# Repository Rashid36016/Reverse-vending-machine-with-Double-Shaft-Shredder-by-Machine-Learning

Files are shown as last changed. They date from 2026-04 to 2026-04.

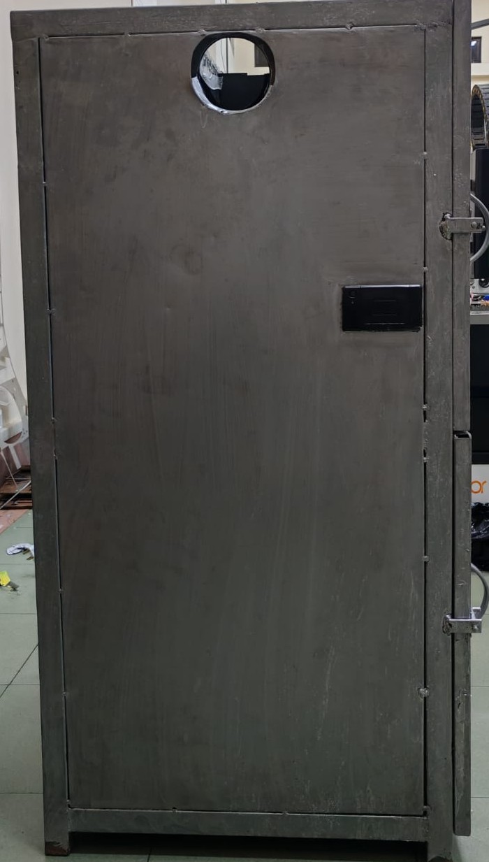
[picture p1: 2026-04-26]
Photos/Front view.jpeg

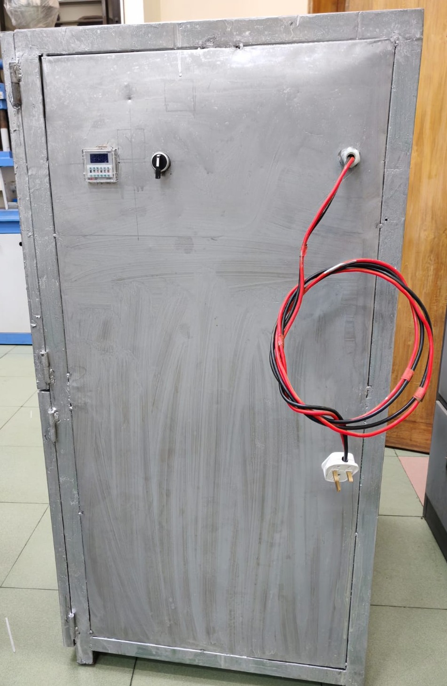
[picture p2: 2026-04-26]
Photos/Back view.jpeg

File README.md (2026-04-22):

# Reverse-vending-machine-with-Double-Shaft-Shredder-by-Machine-Learning

## Project Overview

This project presents a smart Reverse Vending Machine (RVM) designed to accept recyclable plastic bottles, verify them using artificial intelligence and sensor-based validation, and process them using a double shaft shredding mechanism.

The system integrates AI, embedded systems, and mechanical design to create an efficient and automated recycling solution.

---

## Objectives

* To automate plastic bottle collection and validation
* To reduce waste volume through shredding
* To prevent invalid inputs using AI and sensors
* To develop an integrated mechatronic recycling system

---

## Key Features

* AI-based object detection using YOLO
* Real-time image capture using ESP32-S3 CAM
* Sensor-based validation (IR / proximity)
* Double shaft shredding system
* Automatic and timed motor control
* Feedback system (LED / thermal printer)

---

## System Architecture

### 1. Detection Layer (Artificial Intelligence)

The system captures images using the ESP32-S3 CAM and processes them through a YOLO-based object detection model to identify whether the inserted object is a valid plastic bottle.

### 2. Validation Layer (Sensors)

Sensors are used to confirm the presence and correctness of the object, reducing false positives and ensuring reliability.

### 3. Processing Layer (Mechanical System)

A double shaft shredder is used to crush the bottle. This reduces volume and prepares the material for recycling.

---

## Working Principle

1. The user inserts a plastic bottle
2. The camera captures an image
3. The YOLO model performs object detection
4. Sensors validate the input
5. If the object is valid:

   * The shredder motor is activated
6. The bottle is shredded
7. The system provides output feedback

---

## Shredder Mechanism

The system utilizes a double shaft shredding mechanism:

* Two shafts rotate in opposite directions
* Blades mounted on the shafts grip and cut the material
* This configuration improves efficiency and reduces the risk of jamming

---

## Control System

### Automatic Mode

The shredder is activated automatically upon successful detection and validation.

### Timed Mode

The motor operates for a predefined duration to prevent overload and ensure safe operation.

---

## Hardware Components

* ESP32
* ESP32-S3 CAM
* Motor driver
* DC motors
* IR / proximity sensors
* Thermal printer
* Power supply (SMPS)

---

## Software Components

* Arduino IDE (ESP32 programming)
* Python (YOLO model implementation)
* Embedded C/C++

---

## Applications

* Smart recycling systems
* Educational institutions
* Commercial areas (shopping malls)
* Smart city infrastructure

---

## Advantages

* Encourages recycling behavior
* Reduces waste volume
* Minimizes human intervention
* Integrates AI with mechanical processing

---

## Future Work

* Integration of a reward-based system
* Mobile application support
* Cloud-based monitoring
* Improved detection accuracy

---

## Author

Rashid
Industrial and Production Engineering Student

---

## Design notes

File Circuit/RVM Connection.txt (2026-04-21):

RVM System Connection:

Servo-1: Signal -> GPIO 4 , VCC -> Buck 5V , GND -> Buck GND
Servo-2: Signal -> GPIO 5 , VCC -> Buck 5V , GND -> Buck GND

Green LED   VCC -> GPIO 12 , GND -> SMPS GND
Red LED     VCC -> GPIO 13 , GND -> SMPS GND
Red LED     VCC -> GPIO 18 , GND -> SMPS GND
Orange LED  VCC -> GPIO 21 , GND -> SMPS GND
Blue LED    VCC -> GPIO 22 , GND -> SMPS GND
White LED   VCC -> GPIO 23 , GND -> SMPS GND

Thermal Printer: RX -> RX , TX -> TX , VCC -> SMPS 12v , GND -> SMPS GND

ESP32: VCC -> Buck 5V , GND -> Buck GND

ESSP32 S3 CAM: USB Port to LAPTOP

Meaning of LED:-
Ready        -> Green LED
STOP         -> Red LED
PROCESSING   -> Yellow LED
SERVO OPEN   -> Orange LED
SERVO CLOSE  -> Blue LED
PRINT        -> White LED

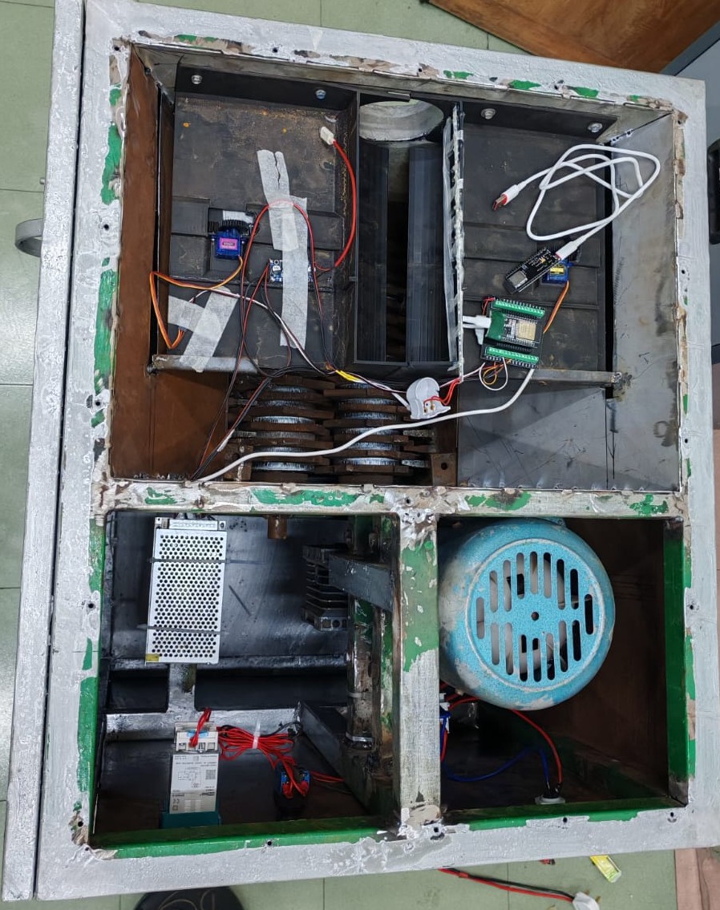
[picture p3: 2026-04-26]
Photos/Top view.jpeg

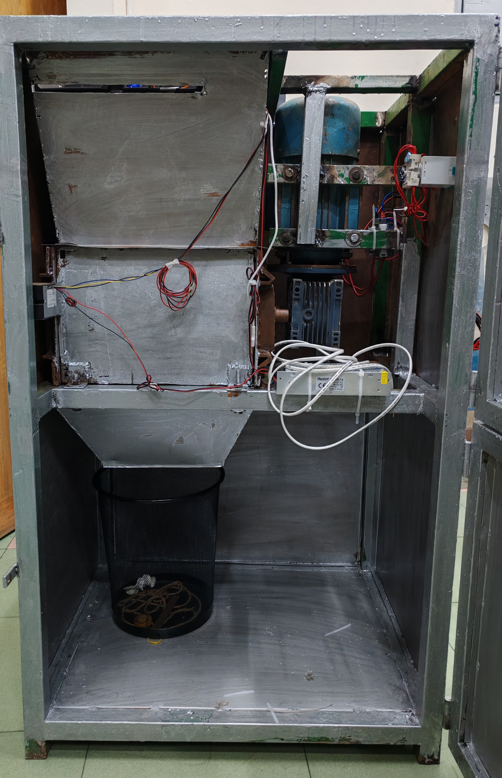
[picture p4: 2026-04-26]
Photos/Side view.jpeg

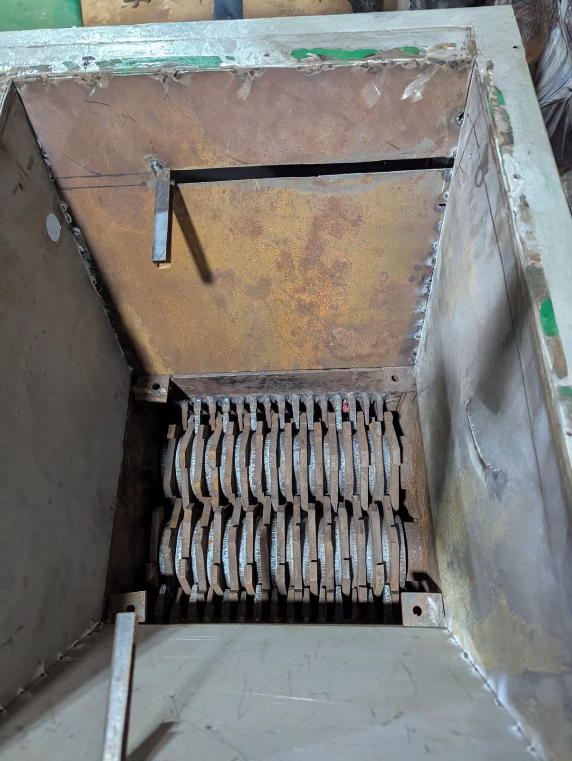
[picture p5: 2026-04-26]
Photos/Top view of the Shredder.jpeg

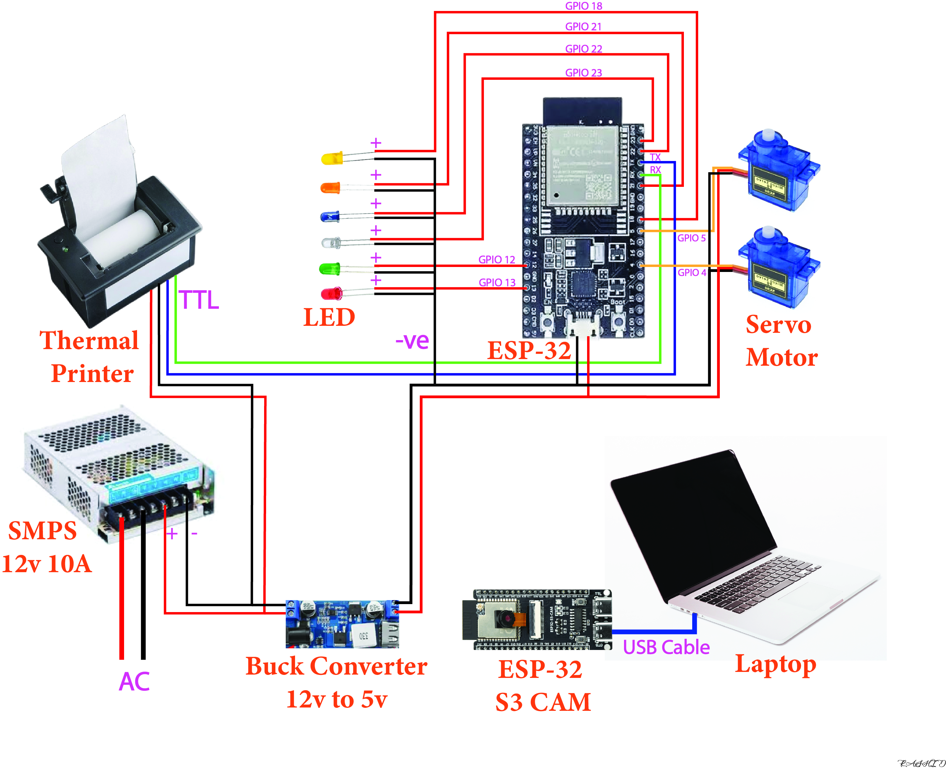
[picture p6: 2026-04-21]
Circuit/Circuite.jpg

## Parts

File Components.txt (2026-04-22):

Components

1. ESP32 Development Board
2. ESP32-S3 Module
3. Servo Motor × 2
4. SMPS Power Supply (12V, 10A)
5. Buck Converter (12V to 5V)
6. Type-C USB Cable
7. Jumper Wires
8. Connecting Wires
9. Thermal Printer
10. LEDs (Red, Blue, Green, White, Yellow, Orange)
11. Laptop / Computer

Tools and Equipment

1. Soldering Iron
2. Soldering Lead
3. Flux (Resin)
4. Double-Sided Tape
5. Glue Gun with Glue Sticks
6. Wire Cutter
7. Anti Cutter
8. Screwdriver 
9. Super Glue
10. 3D Printer

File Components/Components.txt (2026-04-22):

Components

1. ESP32 Development Board
2. ESP32-S3 Module
3. Servo Motor × 2
4. SMPS Power Supply (12V, 10A)
5. Buck Converter (12V to 5V)
6. Type-C USB Cable
7. Jumper Wires
8. Connecting Wires
9. Thermal Printer
10. LEDs (Red, Blue, Green, White, Yellow, Orange)
11. Laptop / Computer
13. Steel Sheet for Frame
14. Shredder Teeth With Shaft (twin shaft)
15. Main Switch
16. Plug × 2
17. AC Motor (2Hp)
18. Gearbox
19. Contantor
20. Overload Relay
21. Time Relay
22. Emergency Stop Button
23. VFD

Tools and Equipment

1. Soldering Iron
2. Soldering Lead
3. Flux (Resin)
4. Double-Sided Tape
5. Glue Gun with Glue Sticks
6. Wire Cutter
7. Anti Cutter
8. Screwdriver 
9. Super Glue
10. 3D Printer

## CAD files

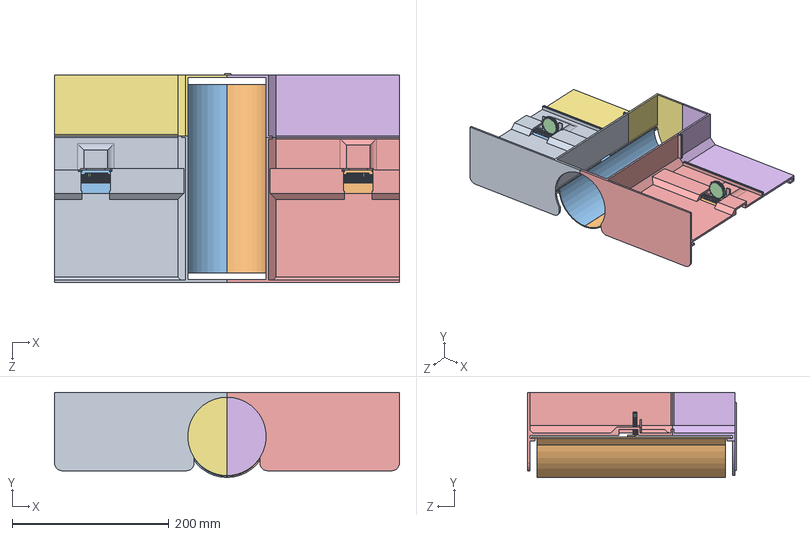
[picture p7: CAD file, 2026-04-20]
3D Parts/3D STLPRT file/Assem1.SLDASM
440.4 x 108.5 x 267.0 mm
Base Left - Back
Base Right - Back
Base Right - Front
Gear x 2
Rack Left
Rack Right
Base Left - Front

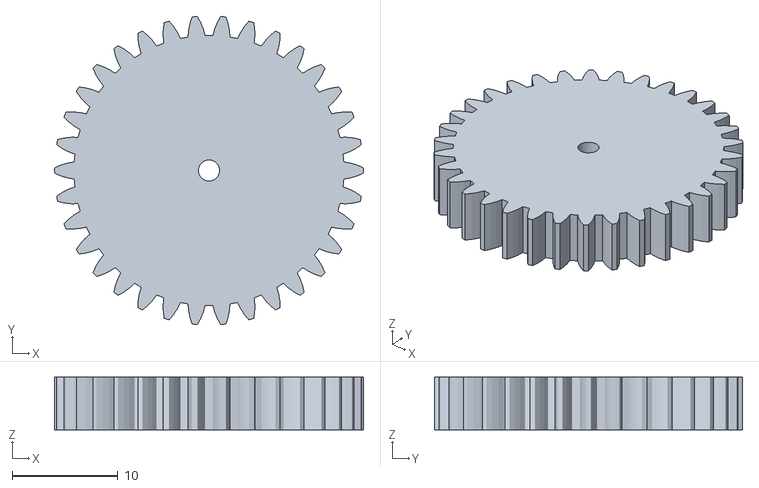
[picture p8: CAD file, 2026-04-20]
3D Parts/3D STL file/Gear.STL
29.2 x 29.1 x 5.00

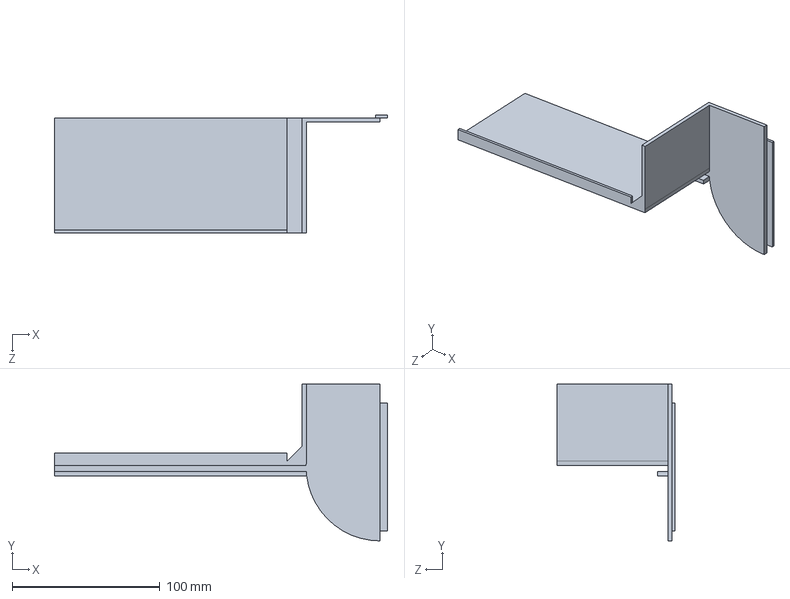
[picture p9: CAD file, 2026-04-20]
3D Parts/3D STLPRT file/Base Left - Back.SLDPRT
225.2 x 106.1 x 80.0 mm

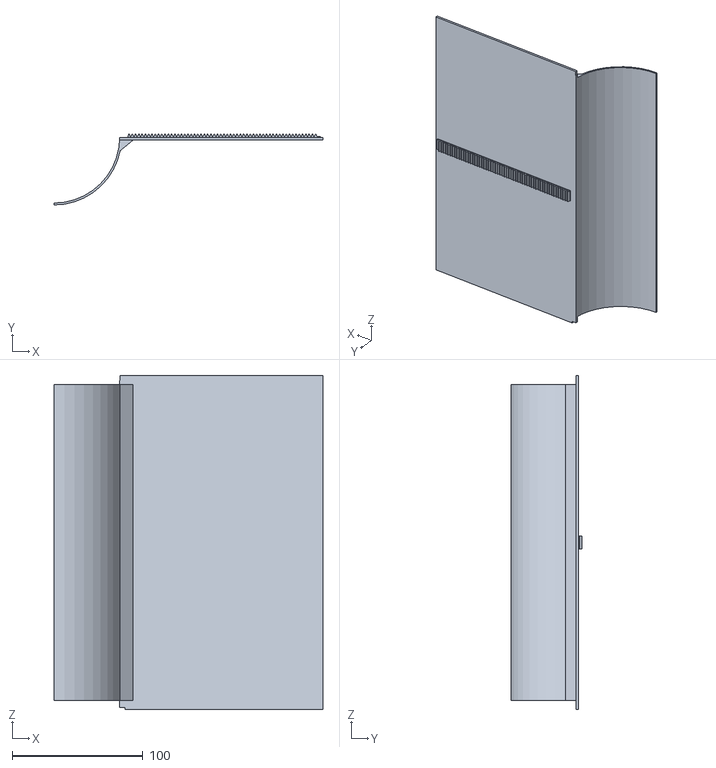
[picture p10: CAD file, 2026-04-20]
3D Parts/3D STL file/Rack Right-2.STL
205.3 x 54.2 x 255.0

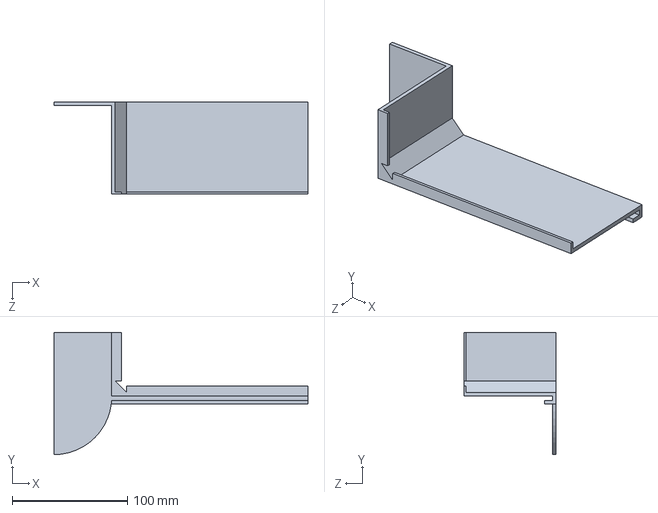
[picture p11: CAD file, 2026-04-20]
3D Parts/3D STLPRT file/Base Right - Back.SLDPRT
220.2 x 106.1 x 80.0 mm

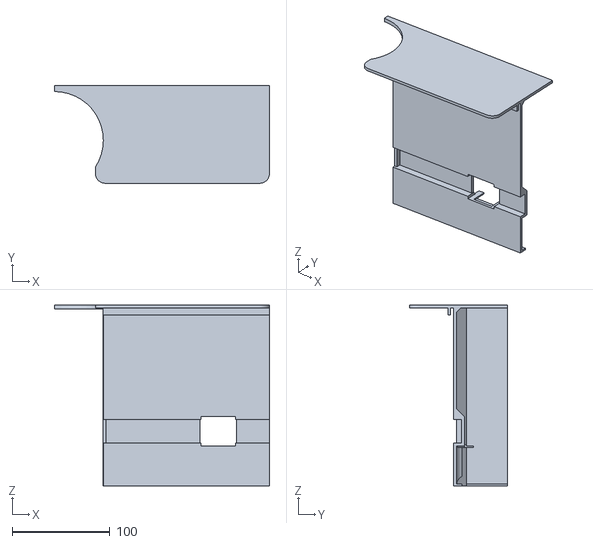
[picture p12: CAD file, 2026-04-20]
3D Parts/3D STL file/Base Right - Front-1.STL
220.2 x 100.0 x 185.0

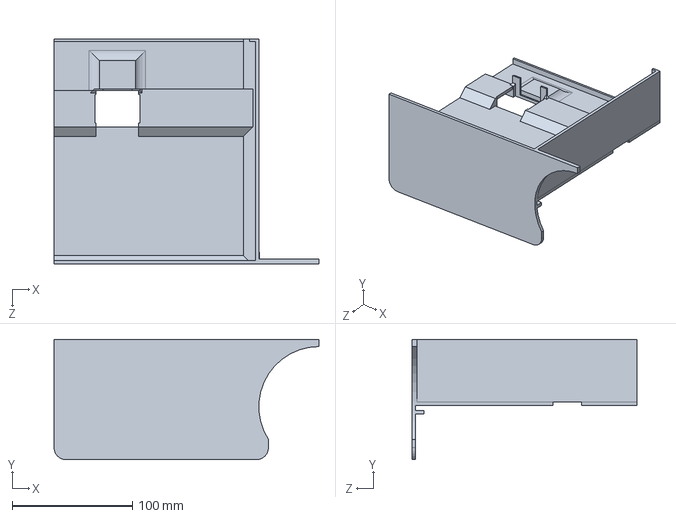
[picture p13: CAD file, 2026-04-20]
3D Parts/3D STLPRT file/Base Left - Front.SLDPRT
220.2 x 100.0 x 187.0 mm

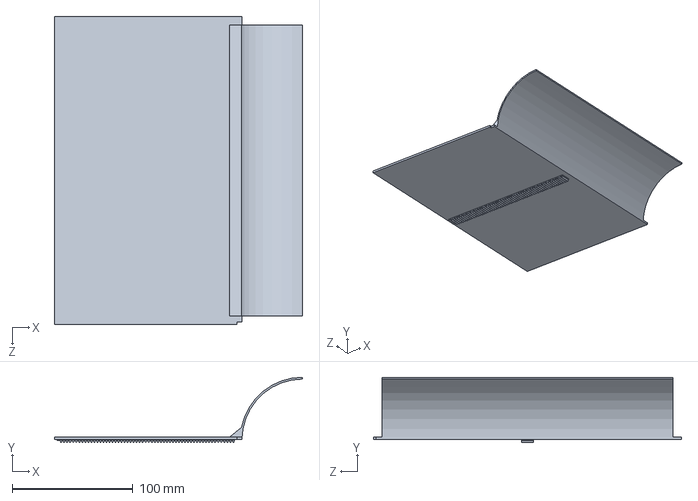
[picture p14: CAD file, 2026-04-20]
3D Parts/3D STLPRT file/Rack Left.SLDPRT
205.3 x 54.2 x 255.0 mm

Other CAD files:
3D Parts/3D STL file/Base Left - Back-1.STL
3D Parts/3D STLPRT file/Base Right - Front.SLDPRT
3D Parts/3D STL file/Base Right - Back-1.STL
3D Parts/3D STL file/Base Left - Front-1.STL
3D Parts/3D STLPRT file/Gear.SLDPRT
3D Parts/3D STL file/Rack Left-2.STL
3D Parts/3D STLPRT file/Rack Right.SLDPRT

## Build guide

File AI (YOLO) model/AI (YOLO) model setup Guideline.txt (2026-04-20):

Windows 11 এ YOLO setup + check 👇

STEP 1: Python install (Windows 11)
Download: 👉 https://www.python.org/downloads/windows/
Install করার সময় IMPORTANT: ✔ “Add Python to PATH” ✔️ (এইটা অবশ্যই tick দাও)

STEP 2: Test Python install
CMD (Command Prompt) খুলে লিখো:
python --version
Output আসবে → দেখতে পাবে Python version

STEP 3: YOLO + Libraries install
CMD এ এইটা paste করো: pip install ultralytics opencv-python requests
Problem হলে fix
❌ pip not recognized
python -m pip install ultralytics 

STEP 4: Test YOLO install
CMD এ লিখো: yolo
Output আসলে → install OK

STEP 4: Simple YOLO test (image)
Open Notepad → Paste 
////
Codes is in next folder Folder Name: YOLO model codes File Name: test
///
ক্লিক Save → Name: test.py → Save as type: All files → Path: C - User - Lenovo - yolo_project

Step 5: Run করো
CMD (Command Prompt) খুলে লিখো:
python test.py
Result window open হবে
Object দেখতে পাবে

STEP 6: Camera test (PC webcam)
Open Notepad → Paste below codes
///
Codes is in next folder Folder Name: YOLO model codes File Name: stream_test
///
ক্লিক Save → Name: stream_test.py → Save as type: All files → Path: C - User - Lenovo - yolo_project

STEP 7: ESP32 Cam stream test
CMD (Command Prompt) খুলে লিখো:
stream_test.py
Result window open হবে
Object detect দেখতে পাবে

STEP 8: Filter Bottle test (PC webcam)
Open Notepad → Paste below codes
///
Codes is in next folder Folder Name: YOLO model codes File Name: filtered_yolo
///
ক্লিক Save → Name: filtered_yolo.py → Save as type: All files → Path: C - User - Lenovo - yolo_project

STEP 9: ESP32 Cam stream test
CMD (Command Prompt) খুলে লিখো:
filtered_yolo.py
Result window open হবে
Only bottle detect করবে।

STEP 10: Main code (It will use from now)
Open Notepad → Paste below codes
///
Codes is in next folder Folder Name: YOLO model codes File Name: main_control
///
ক্লিক Save → Name: main_control.py → Save as type: All files → Path: C - User - Lenovo - yolo_project

STEP 11: ESP32 Activities
Connect ESP32 with PC and connect LEDs with ESP32
CMD (Command Prompt) খুলে লিখো:
main_control.py
Result window open হবে
ESP32 এর activities দেখতে পাবে।

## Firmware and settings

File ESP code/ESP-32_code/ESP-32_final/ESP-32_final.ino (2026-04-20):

#include <ESP32Servo.h>

// =============================
// ===== USER CHANGE ZONE =====
// =============================

#define SERVO1_PIN 4
#define SERVO2_PIN 5

#define READY_LED 12        //Ready for taking bottle
#define STOP_LED 13         //Not ready for taking bottle
#define PROCESSING_LED 18   //Processing 
#define SERVO_OPEN_LED 21   //Get is opening
#define SERVO_CLOSE_LED 22  //Get is closing
#define PRINT_LED 23        //Voucher printing

// Printer UART pins
#define PRINTER_RX 16    // ESP32 receive from printer (optional)
#define PRINTER_TX 17    // ESP32 transmit to printer RX

// Servo speed control
#define SERVO_STEP_DELAY 1
#define SERVO_STEP_SIZE 5

// Servo angles
#define SERVO1_OPEN_ANGLE 180
#define SERVO1_CLOSE_ANGLE 0

#define SERVO2_OPEN_ANGLE 0
#define SERVO2_CLOSE_ANGLE 180

// =============================

Servo servo1;
Servo servo2;

HardwareSerial printer(2);   // UART2

int servo1Current = SERVO1_CLOSE_ANGLE;
int servo2Current = SERVO2_CLOSE_ANGLE;

void setup() {

  Serial.begin(115200);

  servo1.attach(SERVO1_PIN);
  servo2.attach(SERVO2_PIN);
  pinMode(PROCESSING_LED, OUTPUT);
  pinMode(SERVO_OPEN_LED, OUTPUT);
  pinMode(SERVO_CLOSE_LED, OUTPUT);
  pinMode(PRINT_LED, OUTPUT);
  pinMode(READY_LED, OUTPUT);
  pinMode(STOP_LED, OUTPUT);

  // Start printer UART
  printer.begin(9600, SERIAL_8N1, PRINTER_RX, PRINTER_TX);

  readyState();
}


//Receiving data loop
void loop() {
  if (Serial.available()) {
    String cmd = Serial.readStringUntil('\n');

    if (cmd == "TRIGGER") {
      processCycle();
    }
  }
}


// =============================

void moveServoSmooth(Servo &servo, int &currentPos, int targetPos) {

  while (currentPos != targetPos) {

    if (currentPos < targetPos) {
      currentPos += SERVO_STEP_SIZE;
      if (currentPos > targetPos) currentPos = targetPos;
    }
    else {
      currentPos -= SERVO_STEP_SIZE;
      if (currentPos < targetPos) currentPos = targetPos;
    }

    servo.write(currentPos);
//    delay(SERVO_STEP_DELAY);   // শুধু servo step delay থাকবে
  }
}

// =============================

void printVoucher() {

  digitalWrite(PRINT_LED, HIGH);

printer.write(27); 
printer.write(64);

  // -------- RVM System (Center, Big) --------
  printer.write(27); printer.write(97); printer.write(1);   // Center
  printer.write(29); printer.write(33); printer.write(17);  // Big size
  printer.println("RVM System");

  // -------- MIST Cafeteria (Center, Big) --------
  printer.println("MIST Cafeteria");

  // Reset size to normal
  printer.write(29); printer.write(33); printer.write(0);

  // Line
  printer.println("------------------------------------");

  // -------- Bottle Accepted (Left, Small) --------
  printer.write(27); printer.write(97); printer.write(0);   // Left
  printer.println("Bottle Accepted");

  // -------- Reward Label --------
  printer.println("Reward:");

  // -------- 10 (Very Big) --------
  printer.write(27); printer.write(97); printer.write(1);   // Center
  printer.write(29); printer.write(33); printer.write(34);  // Very Big
  printer.print("2");

  // Back to small size
  printer.write(29); printer.write(33); printer.write(0);
  printer.println(" Taka");

  // -------- Thank You (Center, Medium) --------
  printer.write(27); printer.write(97); printer.write(1);   // Center
  printer.write(29); printer.write(33); printer.write(16);  // Medium size
  printer.println("Thank You!");

  // Reset size
  printer.write(29); printer.write(33); printer.write(0);

  // Line
  printer.println("------------------------------------");

  // -------- IPE PD (Right, Smallest) --------
  printer.write(27); printer.write(97); printer.write(2);   // Right
  printer.println("IPE PD");

  printer.println();
  printer.println();

  delay(1000);

  digitalWrite(PRINT_LED, LOW);
}

// =============================

void processCycle() {

  digitalWrite(READY_LED, LOW);
  digitalWrite(STOP_LED, HIGH);
  digitalWrite(PROCESSING_LED, HIGH);


  delay(250);


// Servo open
  digitalWrite(SERVO_OPEN_LED, HIGH);
  moveServoSmooth(servo1, servo1Current, SERVO1_OPEN_ANGLE);
  moveServoSmooth(servo2, servo2Current, SERVO2_OPEN_ANGLE);
  digitalWrite(SERVO_OPEN_LED, LOW);


  delay(250);


// Print Voucher
  printVoucher();


  delay(500);


// Servo close
  digitalWrite(SERVO_CLOSE_LED, HIGH);
  moveServoSmooth(servo1, servo1Current, SERVO1_CLOSE_ANGLE);
  moveServoSmooth(servo2, servo2Current, SERVO2_CLOSE_ANGLE);
  digitalWrite(SERVO_CLOSE_LED, LOW);


  delay(2000);
  readyState();
}

// =============================

void readyState() {

// Initial states 
digitalWrite(READY_LED, HIGH); 
digitalWrite(STOP_LED, LOW); 
digitalWrite(PROCESSING_LED, LOW); 
digitalWrite(SERVO_OPEN_LED, LOW); 
digitalWrite(SERVO_CLOSE_LED, LOW); 
digitalWrite(PRINT_LED, LOW);

}

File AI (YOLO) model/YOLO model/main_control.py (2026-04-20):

from ultralytics import YOLO
import cv2
import time
import serial

# ==============================
# ===== USER CHANGE ZONE =======
# ==============================

STREAM_URL = "http://192.168.0.102:81/stream"

SERIAL_PORT = "COM5"      # <-- Change this to your ESP32 control board COM
BAUD_RATE = 115200

CONF_THRESHOLD = 0.30     # Minimum confidence
DETECTION_HOLD_TIME = 0.003 # Bottle must exist for 1 mili sec
LOCK_TIME = 3             # Prevent re-trigger time

# ==============================

model = YOLO("yolov8n.pt")
cap = cv2.VideoCapture(STREAM_URL)
ser = serial.Serial(SERIAL_PORT, BAUD_RATE)

detection_start = None
last_trigger_time = 0

while True:
    ret, frame = cap.read()
    if not ret:
        break

    results = model(frame, conf=CONF_THRESHOLD)

    bottle_detected = False

    for r in results:
        for box in r.boxes:
            cls_id = int(box.cls[0])
            class_name = model.names[cls_id]
            conf = float(box.conf[0])

            if class_name == "bottle" and conf >= CONF_THRESHOLD:
                bottle_detected = True

    current_time = time.time()

    if bottle_detected:
        if detection_start is None:
            detection_start = current_time

        if (current_time - detection_start >= DETECTION_HOLD_TIME and
            current_time - last_trigger_time > LOCK_TIME):

            print("Bottle confirmed. Sending trigger...")
            ser.write(b"TRIGGER\n")
            last_trigger_time = current_time
            detection_start = None
    else:
        detection_start = None

    annotated_frame = results[0].plot()
    cv2.imshow("YOLO Control", annotated_frame)

    if cv2.waitKey(1) & 0xFF == ord('q'):
        break

cap.release()
cv2.destroyAllWindows()
ser.close()

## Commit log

2026-04-20 Initial commit - RVMDS project
    Added ESP32 firmware, YOLO detection code, circuit design and 3D models for Reverse Vending Machine project
    [Assem1 - Base Left - Back-1.STL, Assem1 - Base Left - Front-1.STL, Assem1 - Base Right - Back-1.STL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]
2026-04-20 Rename Assem1 - Base Left - Back-1.STL to Base Left - Back-1.STL
    [Base Left - Back-1.STL]
2026-04-20 Rename Assem1 - Rack Right-2.STL to Rack Right-2.STL
    [Rack Right-2.STL]
2026-04-20 Rename Assem1 - Rack Left-2.STL to Rack Left-2.STL
    [Rack Left-2.STL]
2026-04-20 Rename Assem1 - Gear-2.STL to Gear-2.STL
    [Gear-2.STL]
2026-04-20 Rename Assem1 - Gear-1.STL to Gear.STL
    [Gear.STL]
2026-04-20 Rename Assem1 - Base Right - Front-1.STL to Base Right - Front-1.STL
    [Base Right - Front-1.STL]
2026-04-20 Rename Assem1 - Base Right - Back-1.STL to Base Right - Back-1.STL
    [Base Right - Back-1.STL]
2026-04-20 Rename Assem1 - Base Left - Front-1.STL to Base Left - Front-1.STL
    [Base Left - Front-1.STL]
